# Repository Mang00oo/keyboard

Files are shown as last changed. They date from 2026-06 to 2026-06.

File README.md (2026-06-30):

# Keyboard
A keyboard designed for Hackclub Keeb
# Devlog
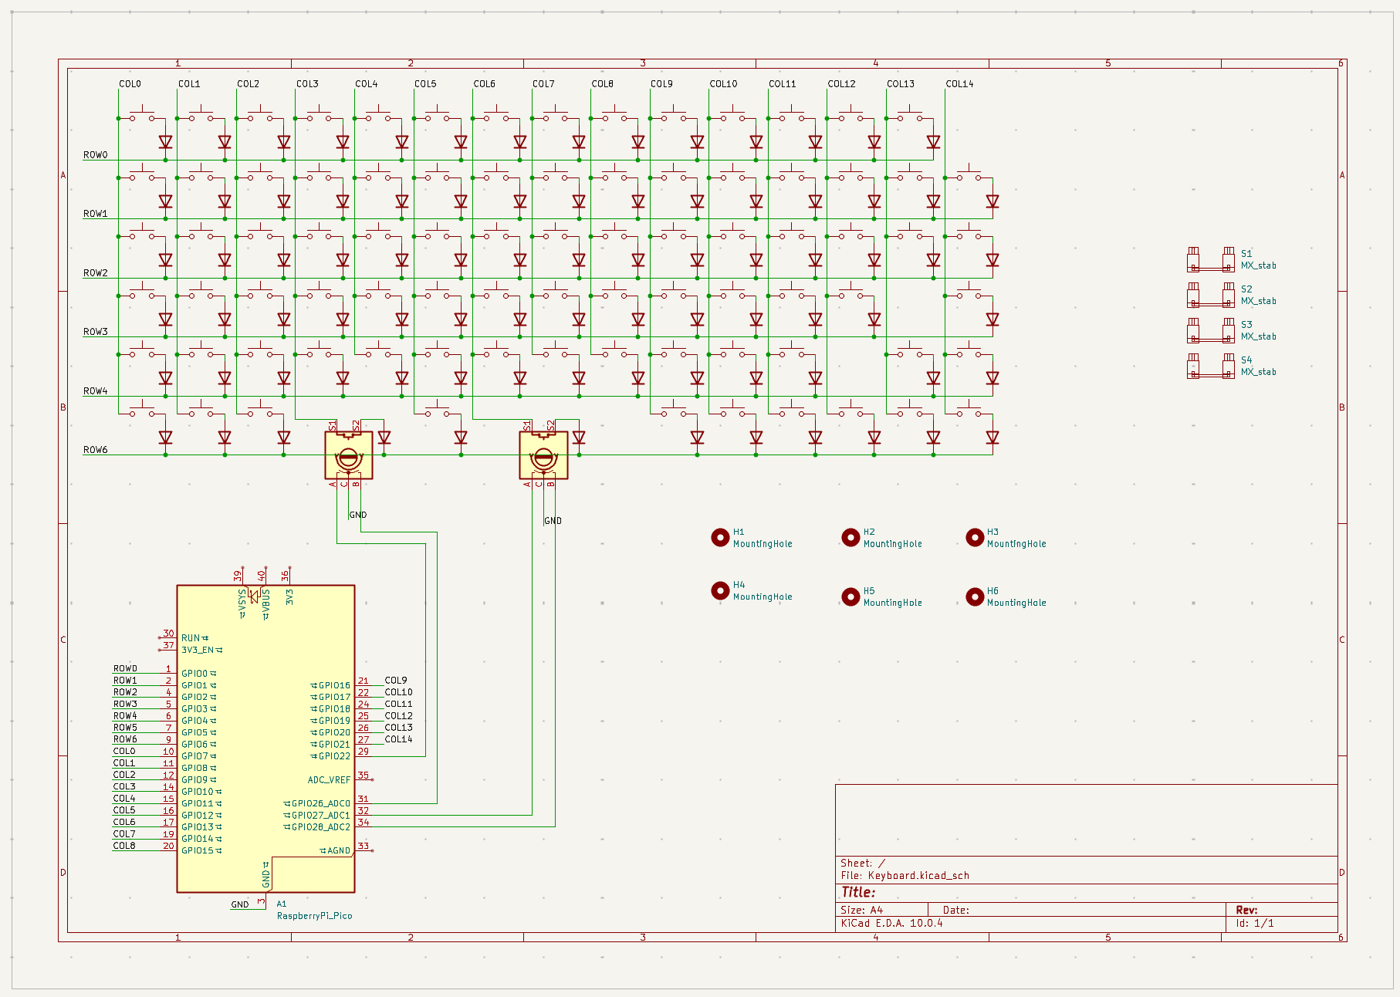
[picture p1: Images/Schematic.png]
Schematic design

First, I decided what I wanted on my keyboard. I went with a 65% layout with 2 rotary encoders. I then layed out the schematic.

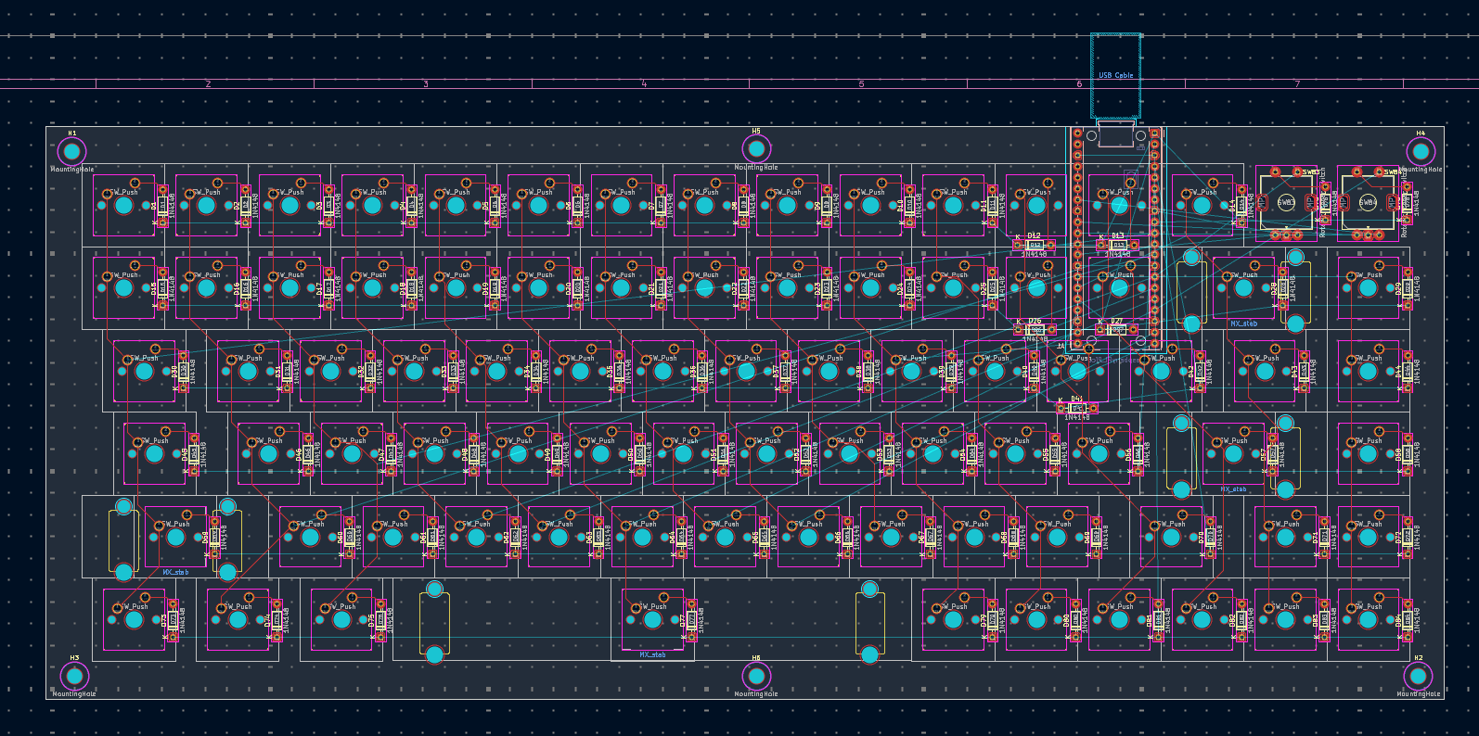
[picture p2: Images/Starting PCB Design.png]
Starting PCB Design

I used Keyboard Layout Editor to make the layout for my keyboard and Keyboard Footprints Placer to place all of my switches and diodes. I then placed the stabilizers, knobs, and pico myself.

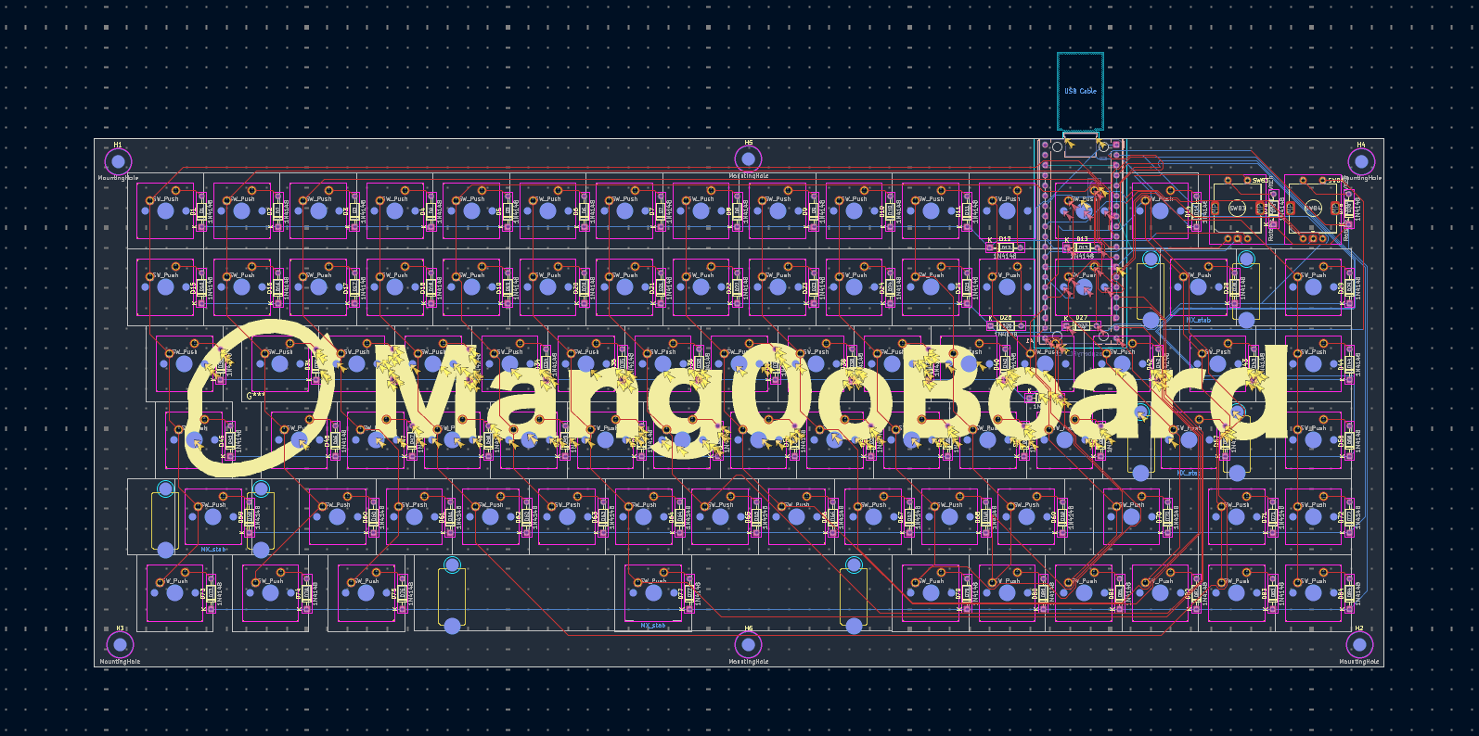
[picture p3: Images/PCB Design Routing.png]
PCB Design Routing

I routed the PCB, but had a lot of trouble with the placement of my pico. I wanted to keep the board as compact as possible, so I placed it on the underside of the board, which made routing way harder.

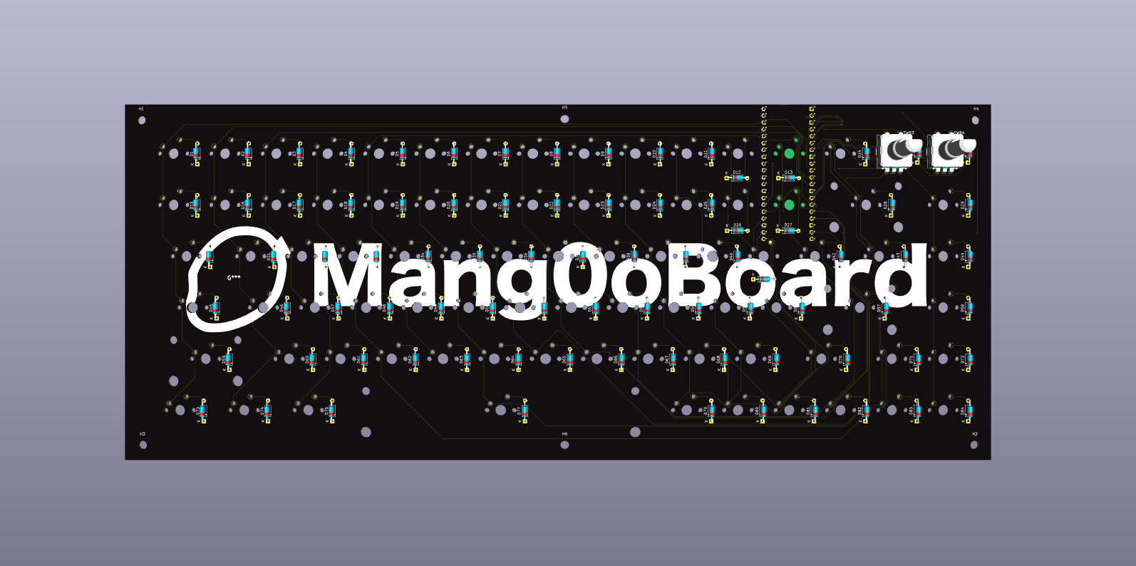
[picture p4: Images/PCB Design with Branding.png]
PCB Design with Branding

I then added a little bit of branding to the board with a nice silkscreen.

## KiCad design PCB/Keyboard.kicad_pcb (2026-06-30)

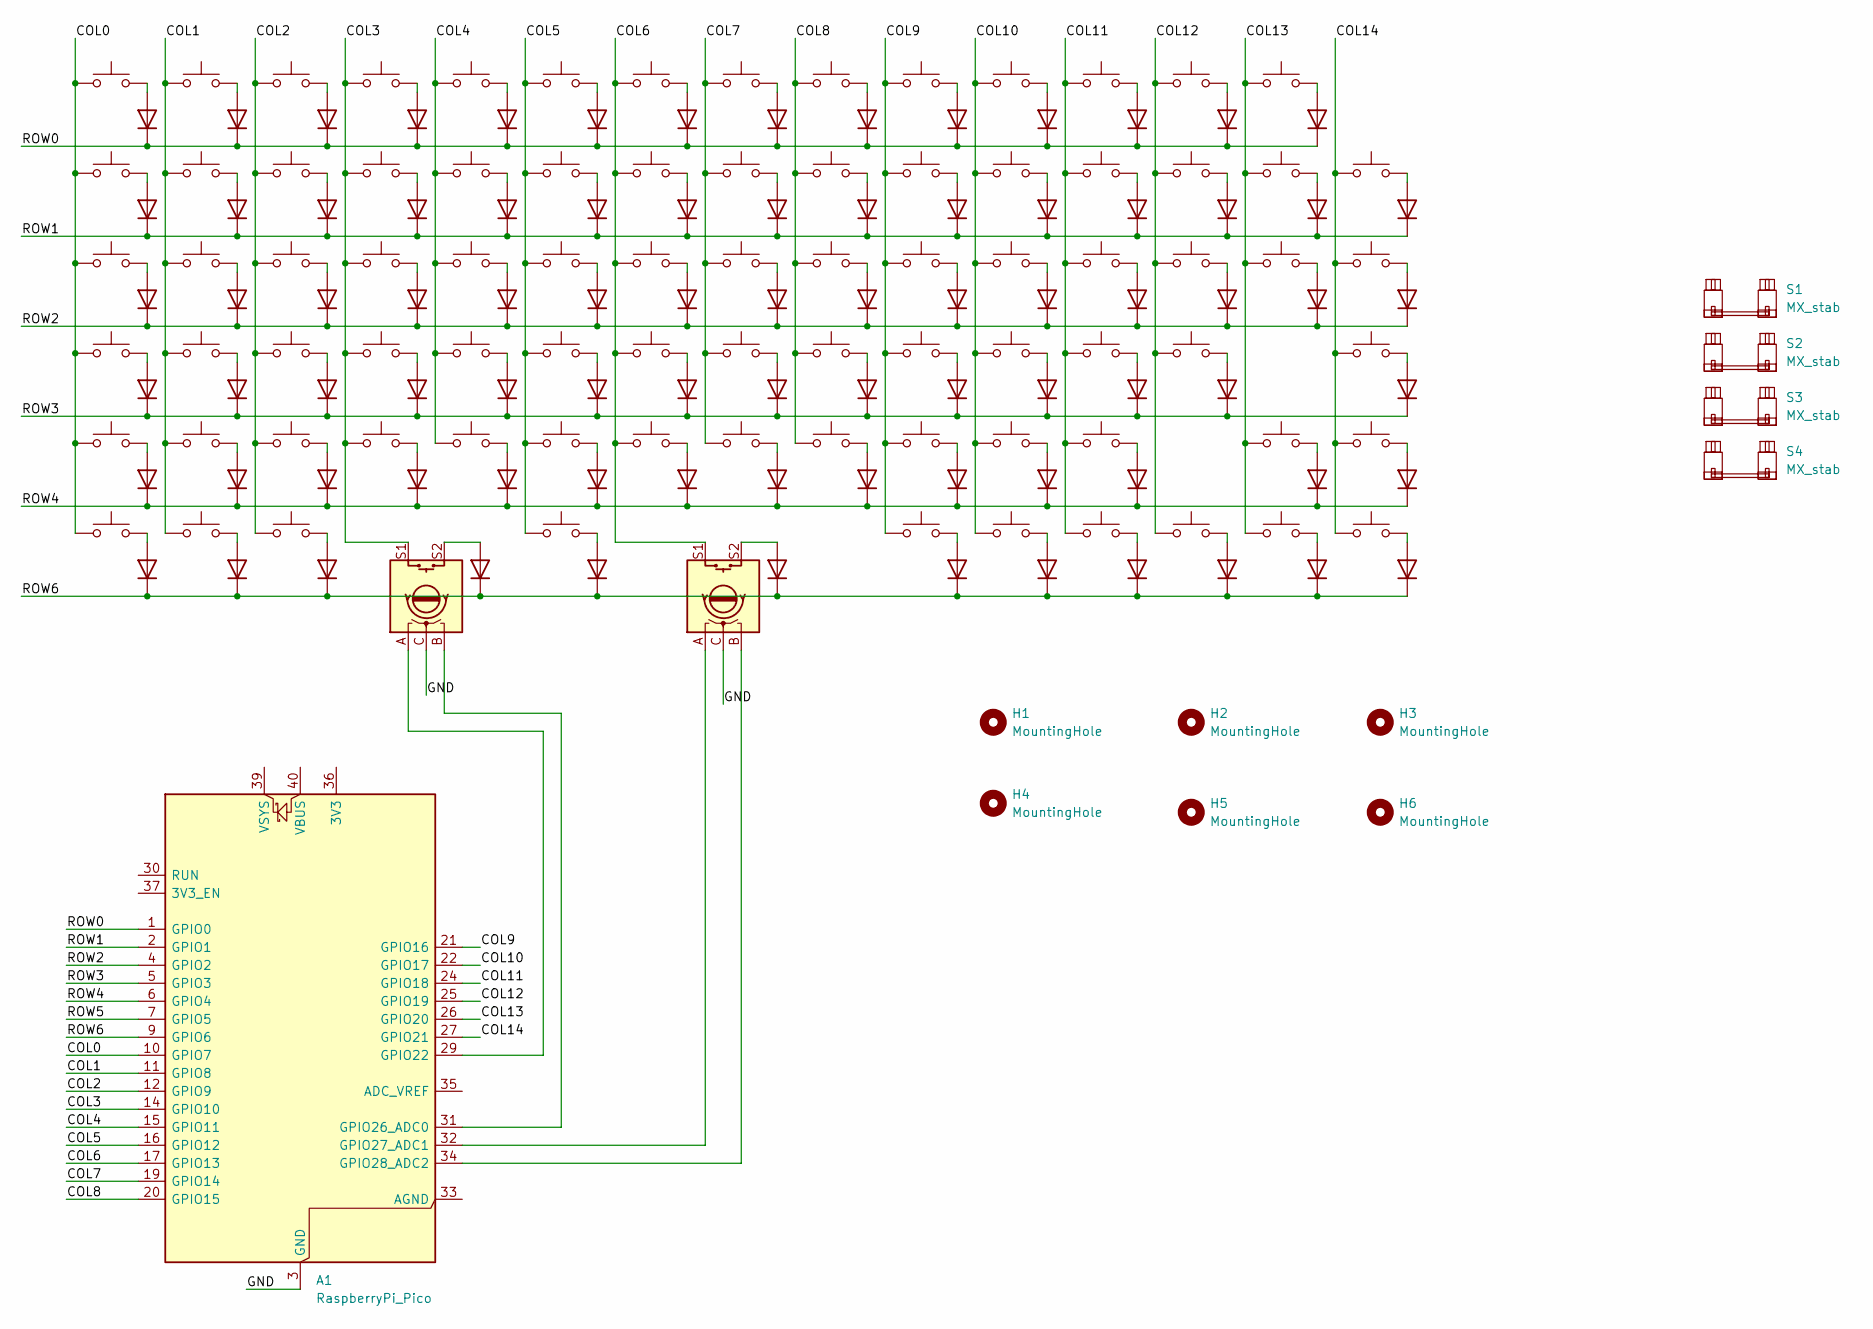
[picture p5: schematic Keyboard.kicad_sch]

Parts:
A1: RaspberryPi_Pico; RaspberryPi_Pico_Common_THT
D1, D2, D3, D4, D5, D6, D7, D8, D9, D10, D11, D12, D13, D14, D15, D16, D17, D18, D19, D20, D21, D22, D23, D24, D25, D26, D27, D28, D29, D30, D31, D32, D33, D34, D35, D36, D37, D38, D39, D40, D41, D42, D43, D44, D45, D46, D47, D48, D49, D50, D51, D52, D53, D54, D55, D56, D57, D58, D59, D60, D61, D62, D63, D64, D65, D66, D67, D68, D69, D70, D71, D72, D73, D74, D75, D76, D77, D78, D79, D80, D81, D82, D83, D84: 1N4148; D_DO-35_SOD27_P7.62mm_Horizontal
H1, H2, H3, H4, H5, H6: MountingHole; MountingHole_3.2mm_M3
S1: MX_stab; STAB_MX_6.25u
S2, S3: MX_stab; STAB_MX_2.25u
S4: MX_stab; STAB_MX_2u
SW1, SW2, SW3, SW4, SW5, SW6, SW7, SW8, SW9, SW10, SW11, SW12, SW13, SW14, SW15, SW16, SW17, SW18, SW19, SW20, SW21, SW22, SW23, SW24, SW25, SW26, SW27, SW28, SW29, SW30, SW31, SW32, SW33, SW34, SW35, SW36, SW37, SW38, SW39, SW40, SW41, SW42, SW43, SW44, SW45, SW46, SW47, SW48, SW49, SW50, SW51, SW52, SW53, SW54, SW55, SW56, SW57, SW58, SW59, SW60, SW61, SW62, SW63, SW64, SW65, SW66, SW67, SW68, SW69, SW70, SW71, SW72, SW73, SW74, SW75, SW76, SW77, SW78, SW79, SW80, SW81, SW82: SW_Push; SW_MX_1u
SW83, SW84: RotaryEncoder_Switch; ROT_Alps_EC11E-Switch

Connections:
/COL0: A1.10 (GPIO7), SW1.1, SW15.1, SW30.1, SW45.1, SW59.1, SW73.1
/COL1: A1.11 (GPIO8), SW2.1, SW16.1, SW31.1, SW46.1, SW60.1, SW74.1
/COL2: A1.12 (GPIO9), SW3.1, SW17.1, SW32.1, SW47.1, SW61.1, SW75.1
/COL3: A1.14 (GPIO10), SW4.1, SW18.1, SW33.1, SW48.1, SW62.1, SW83.S1
/COL4: A1.15 (GPIO11), SW5.1, SW19.1, SW34.1, SW49.1, SW63.1
/COL5: A1.16 (GPIO12), SW6.1, SW20.1, SW35.1, SW50.1, SW64.1, SW76.1
/COL6: A1.17 (GPIO13), SW7.1, SW21.1, SW36.1, SW51.1, SW65.1, SW84.S1
/COL7: A1.19 (GPIO14), SW8.1, SW22.1, SW37.1, SW52.1, SW66.1
/COL8: A1.20 (GPIO15), SW9.1, SW23.1, SW38.1, SW53.1, SW67.1
/COL9: A1.21 (GPIO16), SW10.1, SW24.1, SW39.1, SW54.1, SW68.1, SW77.1
/COL10: A1.22 (GPIO17), SW11.1, SW25.1, SW40.1, SW55.1, SW69.1, SW78.1
/COL11: A1.24 (GPIO18), SW12.1, SW26.1, SW41.1, SW56.1, SW70.1, SW79.1
/COL12: A1.25 (GPIO19), SW13.1, SW27.1, SW42.1, SW57.1, SW80.1
/COL13: A1.26 (GPIO20), SW14.1, SW28.1, SW43.1, SW71.1, SW81.1
/COL14: A1.27 (GPIO21), SW29.1, SW44.1, SW58.1, SW72.1, SW82.1
/GND: A1.3 (GND), A1.8 (GND), A1.13 (GND), A1.18 (GND), A1.23 (GND), A1.28 (GND), A1.38 (GND), SW83.C, SW84.C
/ROW0: A1.1 (GPIO0), D1.1 (K), D2.1 (K), D3.1 (K), D4.1 (K), D5.1 (K), D6.1 (K), D7.1 (K), D8.1 (K), D9.1 (K), D10.1 (K), D11.1 (K), D12.1 (K), D13.1 (K), D14.1 (K)
/ROW1: A1.2 (GPIO1), D15.1 (K), D16.1 (K), D17.1 (K), D18.1 (K), D19.1 (K), D20.1 (K), D21.1 (K), D22.1 (K), D23.1 (K), D24.1 (K), D25.1 (K), D26.1 (K), D27.1 (K), D28.1 (K), D29.1 (K)
/ROW2: A1.4 (GPIO2), D30.1 (K), D31.1 (K), D32.1 (K), D33.1 (K), D34.1 (K), D35.1 (K), D36.1 (K), D37.1 (K), D38.1 (K), D39.1 (K), D40.1 (K), D41.1 (K), D42.1 (K), D43.1 (K), D44.1 (K)
/ROW3: A1.5 (GPIO3), D45.1 (K), D46.1 (K), D47.1 (K), D48.1 (K), D49.1 (K), D50.1 (K), D51.1 (K), D52.1 (K), D53.1 (K), D54.1 (K), D55.1 (K), D56.1 (K), D57.1 (K), D58.1 (K)
/ROW4: A1.6 (GPIO4), D59.1 (K), D60.1 (K), D61.1 (K), D62.1 (K), D63.1 (K), D64.1 (K), D65.1 (K), D66.1 (K), D67.1 (K), D68.1 (K), D69.1 (K), D70.1 (K), D71.1 (K), D72.1 (K)
/ROW5: A1.7 (GPIO5)
/ROW6: A1.9 (GPIO6), D73.1 (K), D74.1 (K), D75.1 (K), D76.1 (K), D77.1 (K), D78.1 (K), D79.1 (K), D80.1 (K), D81.1 (K), D82.1 (K), D83.1 (K), D84.1 (K)
unnamed: A1.29 (GPIO22), SW83.A
unnamed: A1.31 (GPIO26_ADC0), SW83.B
unnamed: A1.32 (GPIO27_ADC1), SW84.A
unnamed: A1.34 (GPIO28_ADC2), SW84.B
unnamed: D1.2 (A), SW1.2
unnamed: D2.2 (A), SW2.2
unnamed: D3.2 (A), SW3.2
unnamed: D4.2 (A), SW4.2
unnamed: D5.2 (A), SW5.2
unnamed: D6.2 (A), SW6.2
unnamed: D7.2 (A), SW7.2
unnamed: D8.2 (A), SW8.2
unnamed: D9.2 (A), SW9.2
unnamed: D10.2 (A), SW10.2
unnamed: D11.2 (A), SW11.2
unnamed: D12.2 (A), SW12.2
unnamed: D13.2 (A), SW13.2
unnamed: D14.2 (A), SW14.2
unnamed: D15.2 (A), SW15.2
unnamed: D16.2 (A), SW16.2
unnamed: D17.2 (A), SW17.2
unnamed: D18.2 (A), SW18.2
unnamed: D19.2 (A), SW19.2
unnamed: D20.2 (A), SW20.2
unnamed: D21.2 (A), SW21.2
unnamed: D22.2 (A), SW22.2
unnamed: D23.2 (A), SW23.2
unnamed: D24.2 (A), SW24.2
unnamed: D25.2 (A), SW25.2
unnamed: D26.2 (A), SW26.2
unnamed: D27.2 (A), SW27.2
unnamed: D28.2 (A), SW28.2
unnamed: D29.2 (A), SW29.2
unnamed: D30.2 (A), SW30.2
unnamed: D31.2 (A), SW31.2
unnamed: D32.2 (A), SW32.2
unnamed: D33.2 (A), SW33.2
unnamed: D34.2 (A), SW34.2
unnamed: D35.2 (A), SW35.2
unnamed: D36.2 (A), SW36.2
unnamed: D37.2 (A), SW37.2
unnamed: D38.2 (A), SW38.2
unnamed: D39.2 (A), SW39.2
unnamed: D40.2 (A), SW40.2
unnamed: D41.2 (A), SW41.2
unnamed: D42.2 (A), SW42.2
unnamed: D43.2 (A), SW43.2
unnamed: D44.2 (A), SW44.2
unnamed: D45.2 (A), SW45.2
unnamed: D46.2 (A), SW46.2
unnamed: D47.2 (A), SW47.2
unnamed: D48.2 (A), SW48.2
unnamed: D49.2 (A), SW49.2
unnamed: D50.2 (A), SW50.2
unnamed: D51.2 (A), SW51.2
unnamed: D52.2 (A), SW52.2
unnamed: D53.2 (A), SW53.2
unnamed: D54.2 (A), SW54.2
unnamed: D55.2 (A), SW55.2
unnamed: D56.2 (A), SW56.2
unnamed: D57.2 (A), SW57.2
unnamed: D58.2 (A), SW58.2
unnamed: D59.2 (A), SW59.2
unnamed: D60.2 (A), SW60.2
unnamed: D61.2 (A), SW61.2
unnamed: D62.2 (A), SW62.2
unnamed: D63.2 (A), SW63.2
unnamed: D64.2 (A), SW64.2
unnamed: D65.2 (A), SW65.2
unnamed: D66.2 (A), SW66.2
unnamed: D67.2 (A), SW67.2
unnamed: D68.2 (A), SW68.2
unnamed: D69.2 (A), SW69.2
unnamed: D70.2 (A), SW70.2
unnamed: D71.2 (A), SW71.2
unnamed: D72.2 (A), SW72.2
unnamed: D73.2 (A), SW73.2
unnamed: D74.2 (A), SW74.2
unnamed: D75.2 (A), SW75.2
unnamed: D76.2 (A), SW83.S2
unnamed: D77.2 (A), SW76.2
unnamed: D78.2 (A), SW84.S2
unnamed: D79.2 (A), SW77.2
unnamed: D80.2 (A), SW78.2
unnamed: D81.2 (A), SW79.2
unnamed: D82.2 (A), SW80.2
unnamed: D83.2 (A), SW81.2
unnamed: D84.2 (A), SW82.2

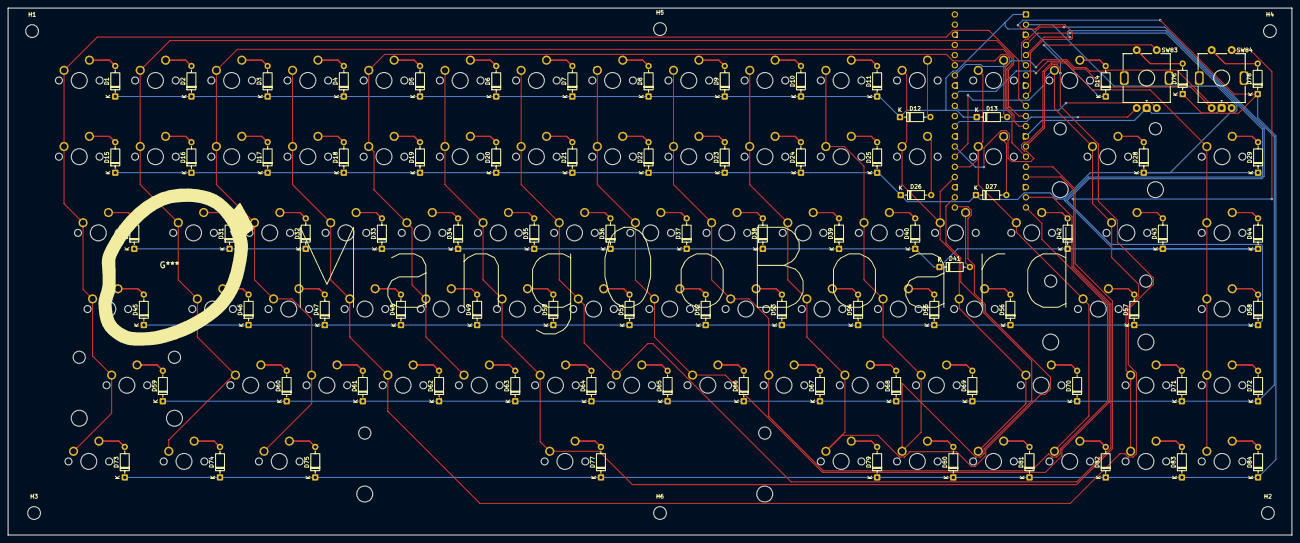
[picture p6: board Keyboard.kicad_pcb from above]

Board: 2 copper layers, 321.0 x 131.8 mm, 179 parts (1 on the bottom side), 110 nets.

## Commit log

2026-06-30 Schematic Screenshot
2026-06-30 Initial KiCad commit
    [Keyboard.kicad_pcb, Keyboard.kicad_sch]
2026-06-30 Finished PCB design
2026-06-30 Reorganized the repo and started writing a devlog in the readme
    [Keyboard.kicad_pcb, Keyboard.kicad_sch]
2026-07-01 Exported gerber files
